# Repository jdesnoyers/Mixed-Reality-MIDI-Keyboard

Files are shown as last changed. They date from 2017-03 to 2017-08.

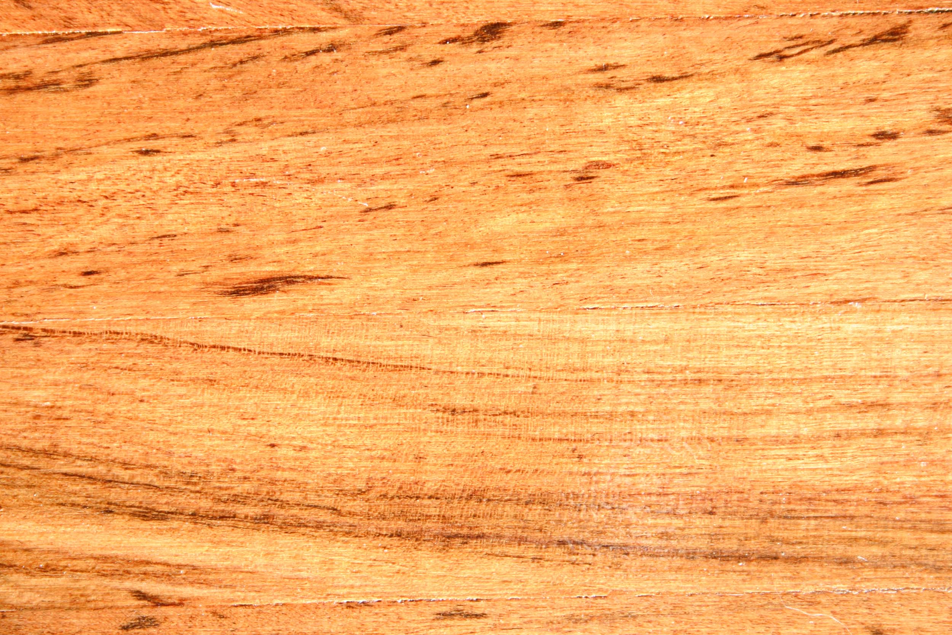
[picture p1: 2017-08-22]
Unity/VR Interactive Keyboard 3/Assets/Models/UV Maps/texturegen_166_6645.jpg

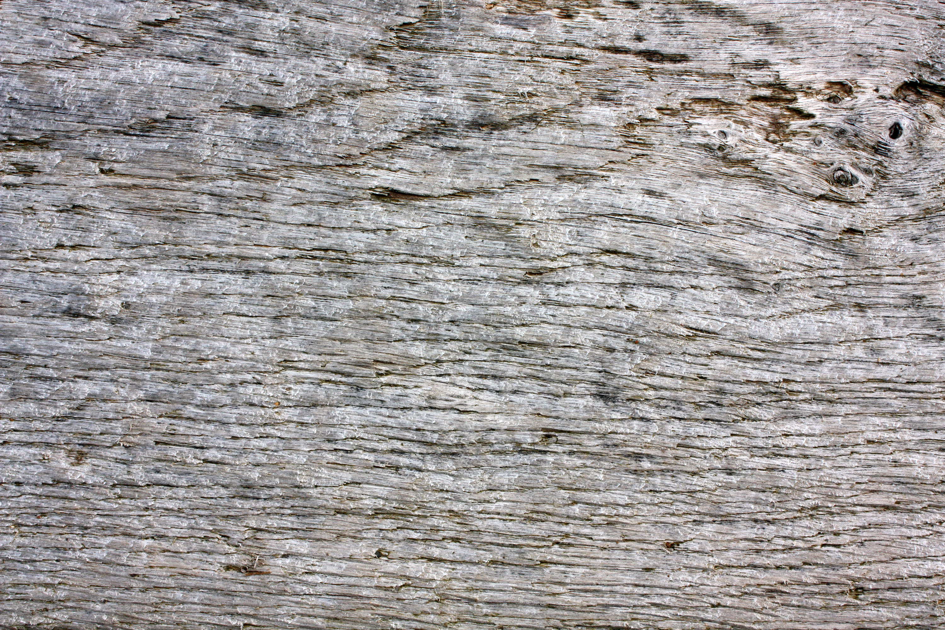
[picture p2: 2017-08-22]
Unity/VR Interactive Keyboard 3/Assets/Models/UV Maps/texturegen_7123.jpg

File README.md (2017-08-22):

# Mixed Reality MIDI Keyboard

This Mixed Reality MIDI Keyboard is an open source system for integrating a MIDI Keyboard into a virtual environment. It includes the design and programming of both the physical keyboard, and the virtual reality environment through which it is interacted with. The system uses a number of devices including the HTC Vive, Vive Tracker, and Leap Motion to locate the user's hands and keyboard.

The keyboard is built from a salvaged keybed, Arduino Mega 2560, and a number of other analog and digital transducers. It communicates using the MIDI protocol, over either MIDI or USB cables allowing it to interface with other stanardized MIDI instruments and digital audio workstations.

## Folders

### Arduino
Program for implementation of physical hardware using Arduino Mega 2560.

### Design Files
3D CAD files, drawings, electrical routing required to build the Keyboard frame and assemble components.

### Unity
Contains required files for Unity project - requires a number of plugins and programs to function properly as listed below:

#### Required Unity Plugins
 - NVIDIA VRWorks
 - TextMesh Pro
 - Leap Motion SDK, hand module and interaction engine module
 
#### Required Programs
 - Unity 2017.1
 - Leap Motion Orion
 - LoopMIDI
 - Hairless MIDIserial
 - Any DAW (Digital Audio Workstation) such as Bitwig Studio or Ableton Live

## Setup

## Operation

---

## Updates

### 10/Aug/2017 - Version 2 - Audio Mostly
This update aligns the software with Version 2 of the physical keyboard. The keyboard has been improved with:
 - matte black interaction surfaces
 - angled upper deck
 - Additional potentiometer and rotary encoder
 - tactile buttons
 - Infrared LEDs with improved, more precise localization capablity

### 27/Mar/2017 - Version 1

#### Changes:
 - Changed to external pull-down resistor configuration in order to simultaneously scan both MK and BR matrices
 - Inputs read directly from registers to reduce scanning time
 - Scanning code optimized to reduce scanning time (currently as low as 470 microseconds when all other functions disabled)
 - MIDI output now sends over USB and MIDI port (TX1)
 - MIDI input (RX1) forwarding to USB
 - Dedicated send/receive MIDI functions
 - #define used in place of constants where possible
 - all variables minimized to take up as little space as possible (eg. using a byte as a boolean array)

#### Additions:
 - 12 input MPR121 Capacitive Array via I2C
 - 60 pixel Adafruit Neopixel LED Strip 
 - Fast LED library to minimize impact on scanning function
 - Pitch Bend control via IR proximity sensor (in progress, may be used as modulation control instead)
 - "Abstraction Layer" slider added
 
#### To Do:
 - Complete Hardware Design & Build
 - Develop Unity based VR platform
 - Integrate MIDI, HTC Vive and Leap Motion
 - Continued Optimization

---

### 27/Feb/2017
Currently a fully functional 61-key midi keyboard with velocity sensing (code is set to 9600 baud for testing)

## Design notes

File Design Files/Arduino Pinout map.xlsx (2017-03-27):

 | Rev 2 |  |  | Resistor to Ground
24 | BR3 | MK3 | 25 | 24 | BR3 | MK3 | 25
26 | MK4 | X | 27 | 26 | MK4 |  | 27
28 | BR4 | X | 29 | 28 | BR4 |  | 29
30 | MK5 | KD0 | 31 | 30 | MK5 |  | 31
32 | BR5 | KD1 | 33 | 32 | BR5 |  | 33
34 | MK6 | KD2 | 35 | 34 | MK6 |  | 35
36 | BR6 | KD3 | 37 | 36 | BR6 |  | 37
38 | MK7 | KD4 | 39 | 38 | MK7 |  | 39
40 | BR7 | KD5 | 41 | 40 | BR7 |  | 41
42 | MK8 | KD6 | 43 | 42 | MK8 |  | 43
44 | BR8 | KD7 | 45 | 44 | BR8 |  | 45
46 | MK9 | BR10 | 47 | 46 | MK9 | BR10 | 47
48 | BR9 | MK10 | 49 | 48 | BR9 | MK10 | 49
 | New
22 | BR3 | MK3 | 23
24 | MK4 | X | 25
26 | BR4 | X | 27
28 | MK5 | KD0 | 29
30 | BR5 | KD1 | 31
32 | MK6 | KD2 | 33
34 | BR6 | KD3 | 35
36 | MK7 | KD4 | 37
38 | BR7 | KD5 | 39
40 | MK8 | KD6 | 41
42 | BR8 | KD7 | 43
44 | MK9 | BR10 | 45
46 | BR9 | MK10 | 47
 | Old
22 | MK10 | BR9 | 23
24 | BR10 | MK9 | 25
26 | KD7 | BR8 | 27
28 | KD6 | MK8 | 29
30 | KD5 | BR7 | 31
32 | KD4 | MK7 | 33
34 | KD3 | BR6 | 35
36 | KD2 | MK6 | 37
38 | KD1 | BR5 | 39
40 | KD0 | MK5 | 41
42 | X | BR4 | 43
44 | X | MK4 | 45
46 | MK3 | BR3 | 47

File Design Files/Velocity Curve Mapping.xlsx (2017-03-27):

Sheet: Sheet1
 |  |  | dTmin | 2442 | resolution
Distance | 0.0001 m |  | dTmax | 100400 | 41.11384111
Delta T (uS) | Velocity | midi out (-127/1040) | midi out (dTmin)
814 | 1.228501229 | 135.5789224 | 129.1106597
1628 | 0.6142506143 | 131.1394593 | 128.0553298
2442 | 0.4095004095 | 126.8422173 | 127
3256 | 0.3071253071 | 122.6826401 | 125.9446702
4070 | 0.2457002457 | 118.6563175 | 124.8893403
4884 | 0.2047502048 | 114.7589808 | 123.8340105
5698 | 0.1755001755 | 110.9864977 | 122.7786807
6512 | 0.1535626536 | 107.3348684 | 121.7233508
7326 | 0.1365001365 | 103.8002214 | 120.668021
8140 | 0.1228501229 | 100.3788091 | 119.6126912
8954 | 0.1116819299 | 97.06700384 | 118.5573613
9768 | 0.1023751024 | 93.86129435 | 117.5020315
10582 | 0.0945000945 | 90.75828179 | 116.4467016
11396 | 0.08775008775 | 87.75467618 | 115.3913718
12210 | 0.0819000819 | 84.84729298 | 114.336042
13024 | 0.07678132678 | 82.03304962 | 113.2807121
13838 | 0.07226477815 | 79.30896233 | 112.2253823
14652 | 0.06825006825 | 76.67214288 | 111.1700525
15466 | 0.06465795939 | 74.11979561 | 110.1147226
16280 | 0.06142506143 | 71.64921439 | 109.0593928
17094 | 0.0585000585 | 69.25777979 | 108.004063
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

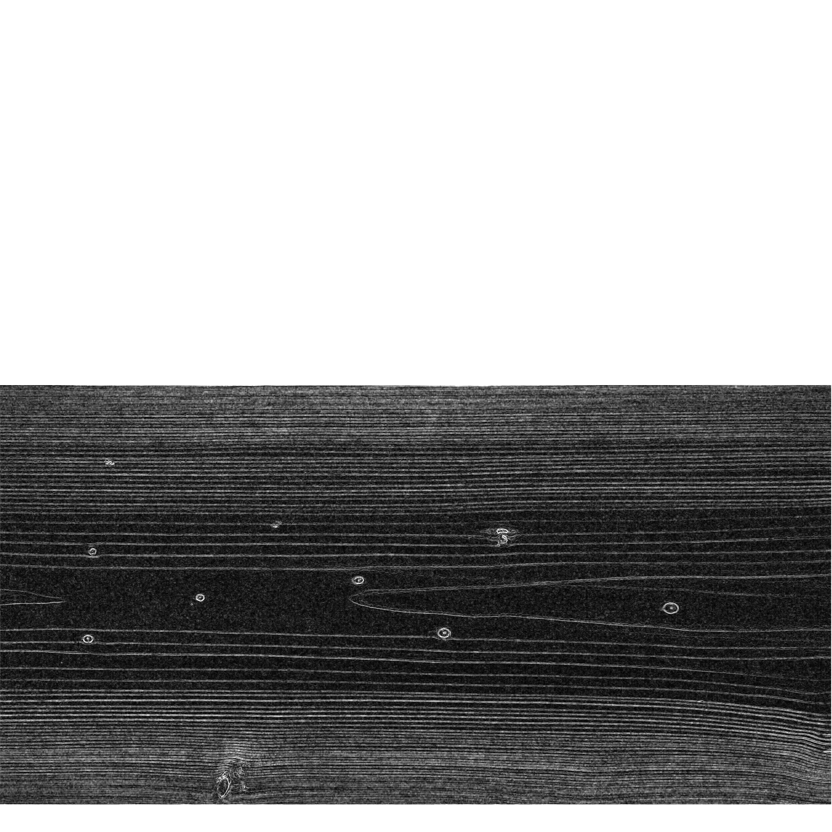
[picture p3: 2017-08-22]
Unity/VR Interactive Keyboard 3/Assets/Models/UV Maps/MR MIDI Keyboard - End Piece Specular.png

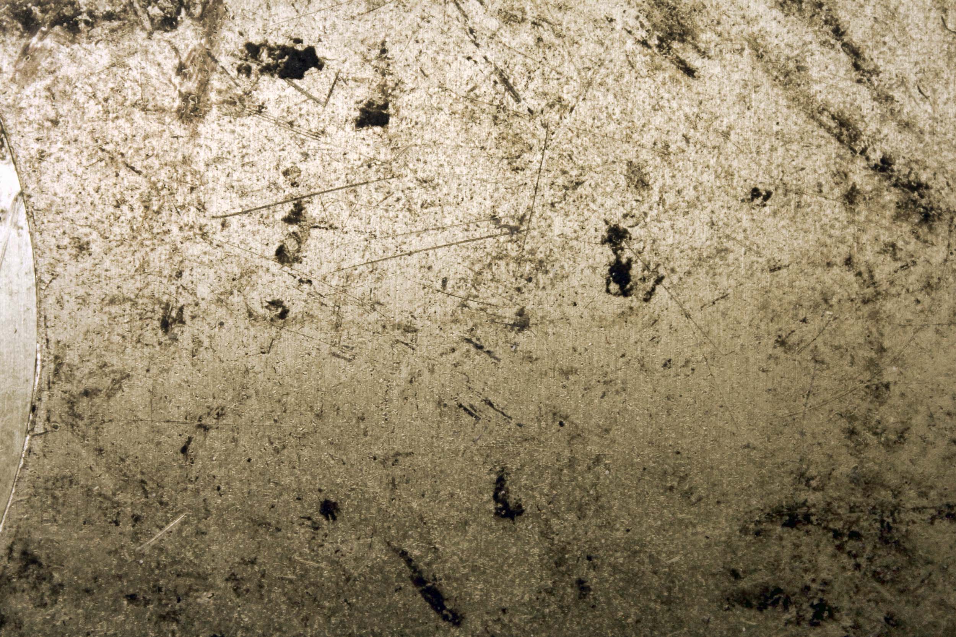
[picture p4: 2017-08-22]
Unity/VR Interactive Keyboard 3/Assets/Models/UV Maps/texturegen_w1098.jpg

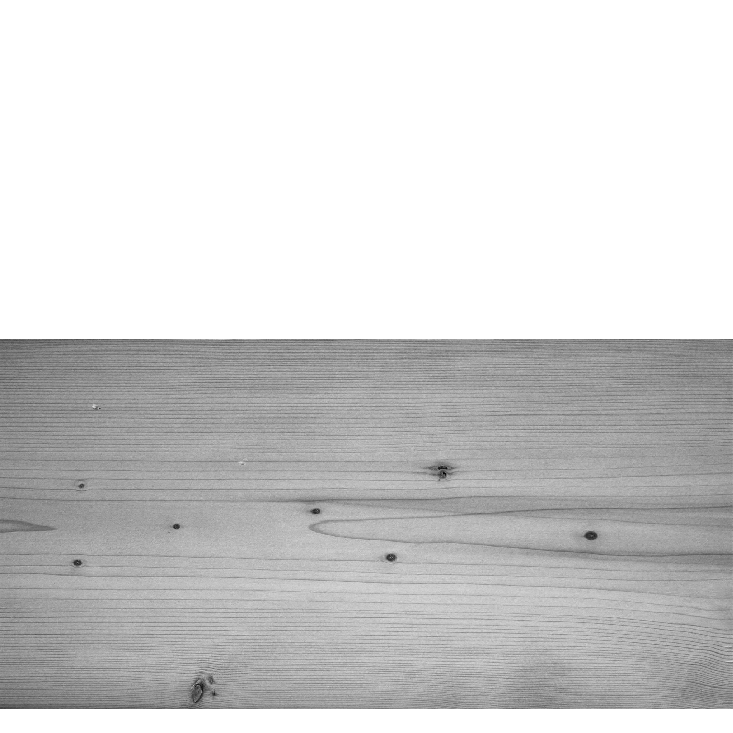
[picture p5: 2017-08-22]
Unity/VR Interactive Keyboard 3/Assets/Models/UV Maps/MR MIDI Keyboard - End Piece Bump.png

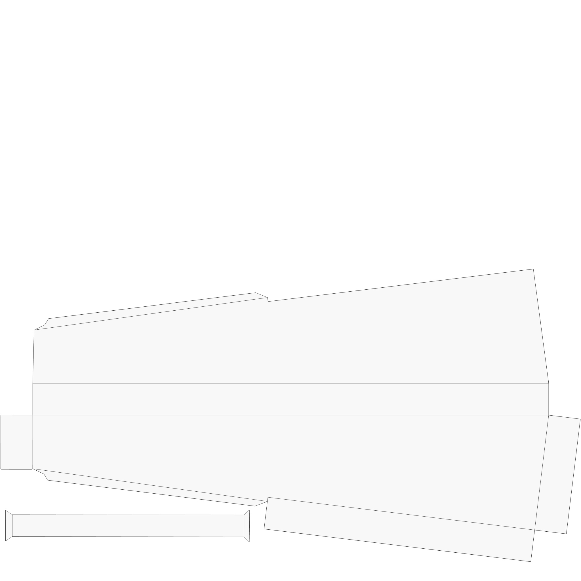
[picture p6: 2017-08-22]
Unity/VR Interactive Keyboard 3/Assets/Models/UV Maps/MR MIDI Keyboard - End Piece UV.png

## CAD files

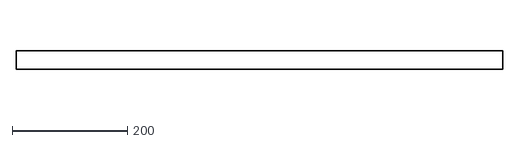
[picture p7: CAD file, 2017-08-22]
Design Files/Mechanical/Outlines/Keyboard Parts - Reinforcement-Rear.dxf
842.0 x 31.8

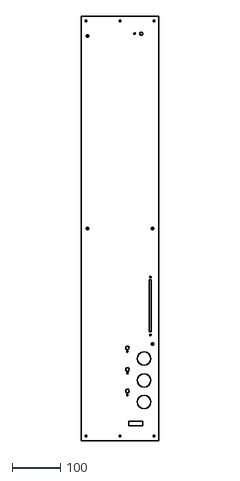
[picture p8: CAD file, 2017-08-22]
Design Files/Mechanical/Outlines/Keyboard Parts - Top Panel.dxf
160.4 x 882.0

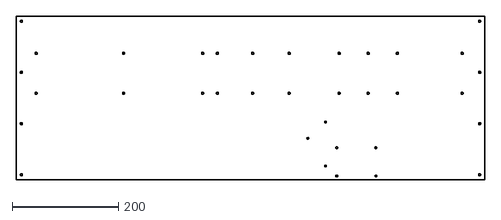
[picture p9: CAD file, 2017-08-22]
Design Files/Mechanical/Outlines/Keyboard Parts - Base Panel.dxf
882.0 x 308.0

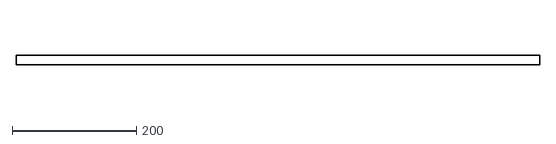
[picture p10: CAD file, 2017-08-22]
Design Files/Mechanical/Outlines/Keyboard Parts - Reinforcement-Front.dxf
842.0 x 15.9

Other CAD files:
Unity/VR Interactive Keyboard 3/Assets/Models/MR MIDI Keyboard.blend

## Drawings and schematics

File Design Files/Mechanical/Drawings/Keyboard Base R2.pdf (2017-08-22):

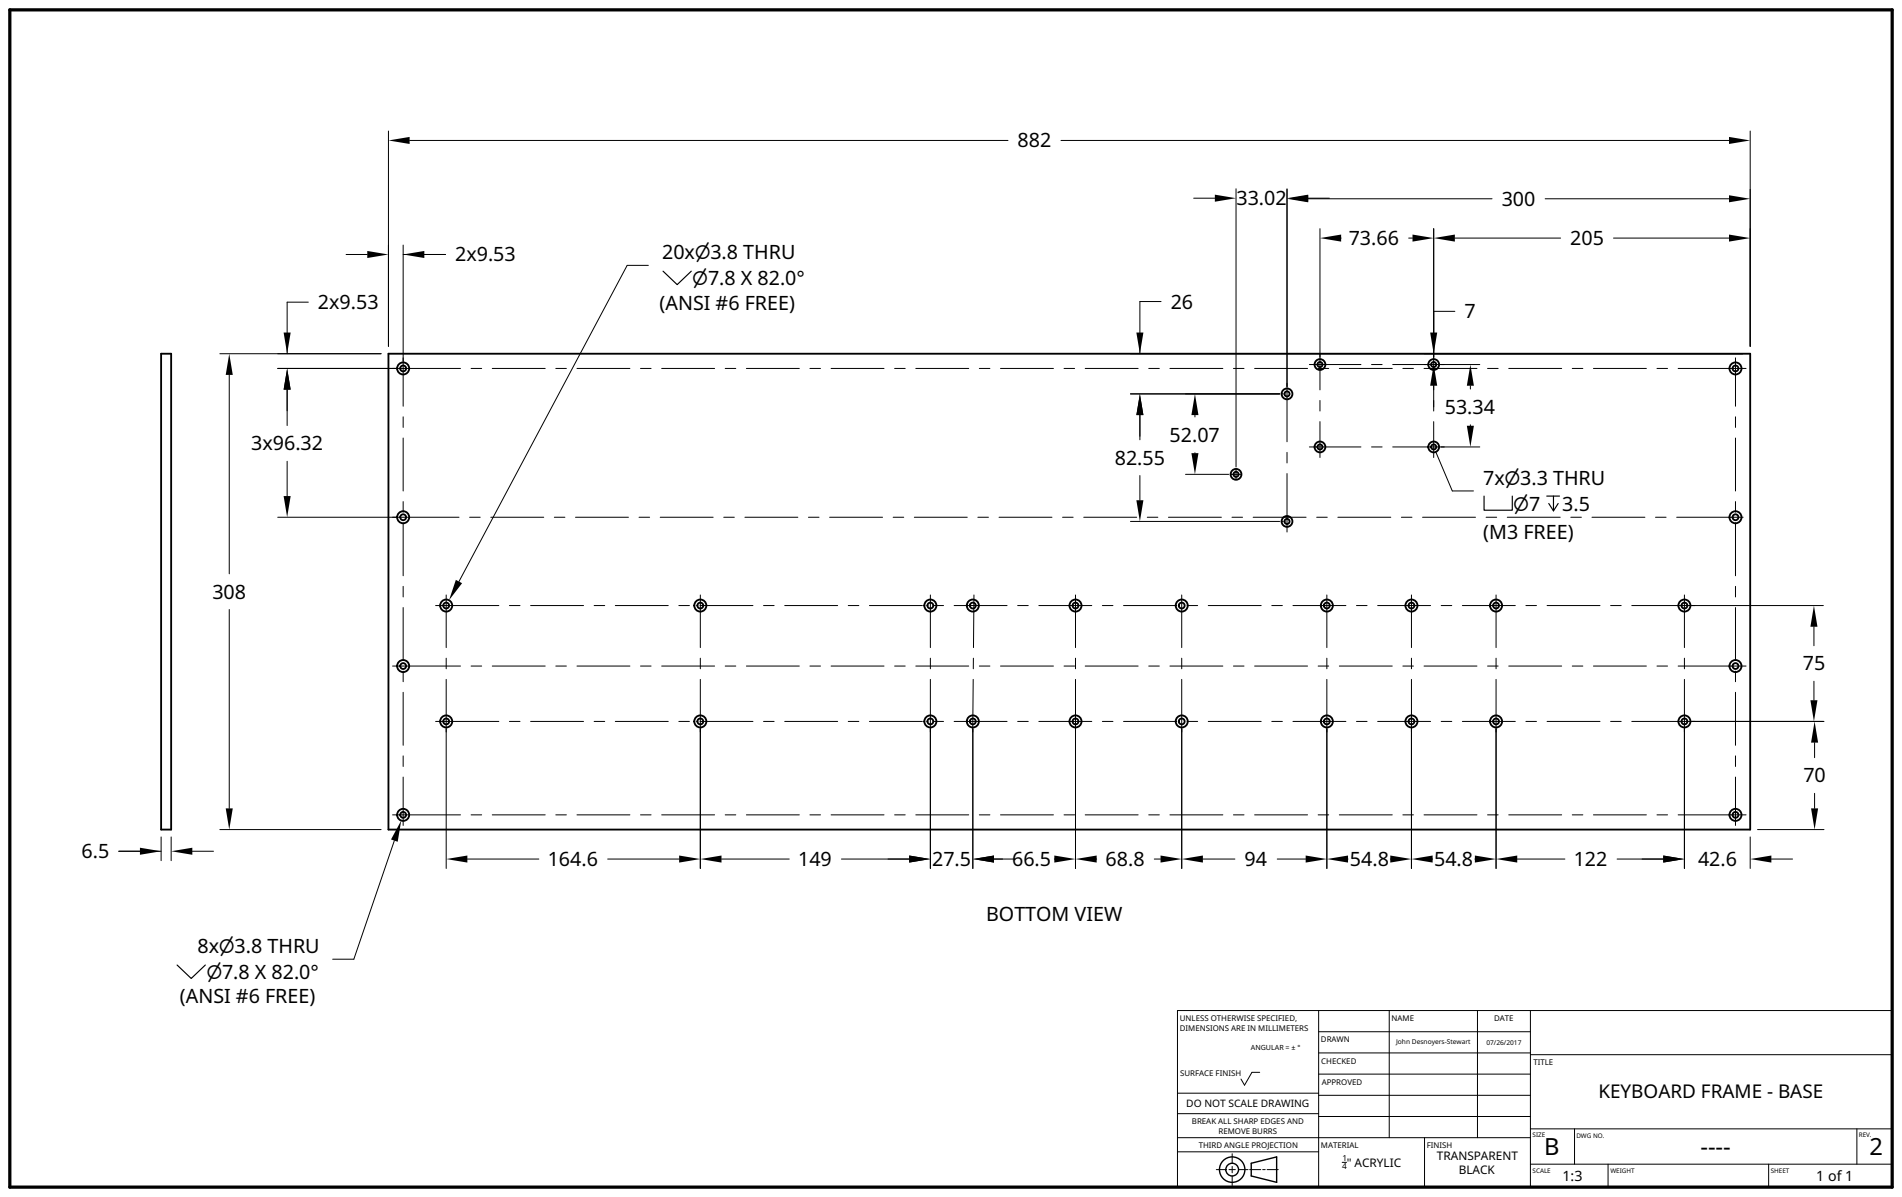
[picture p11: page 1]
MATERIAL; 1 4" ACRYLIC; FINISH TRANSPARENT BLACK; BOTTOM VIEW; 8x3.8 THRU w7.8 X 82.0°; 20x3.8 THRU w7.8 X 82.0° (ANSI #6 FREE); (ANSI #6 FREE); (M3 FREE); 7x3.3 THRU v7 x3.5

UNLESS OTHERWISE SPECIFIED, DIMENSIONS ARE IN MILLIMETERS ANGULAR = ± ° SURFACE FINISH | | NAME | DATE

DRAWN | John Desnoyers-Stewart | 07/26/2017

CHECKED | | | TITLE KEYBOARD FRAME - BASE

APPROVED

DO NOT SCALE DRAWING

BREAK ALL SHARP EDGES AND

REMOVE BURRS
THIRD ANGLE PROJECTION

SIZE B | DWG NO. ---- | REV. 2

SCALE 1:3 | WEIGHT | SHEET

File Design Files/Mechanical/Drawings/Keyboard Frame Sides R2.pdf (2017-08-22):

2x70.67

9.53

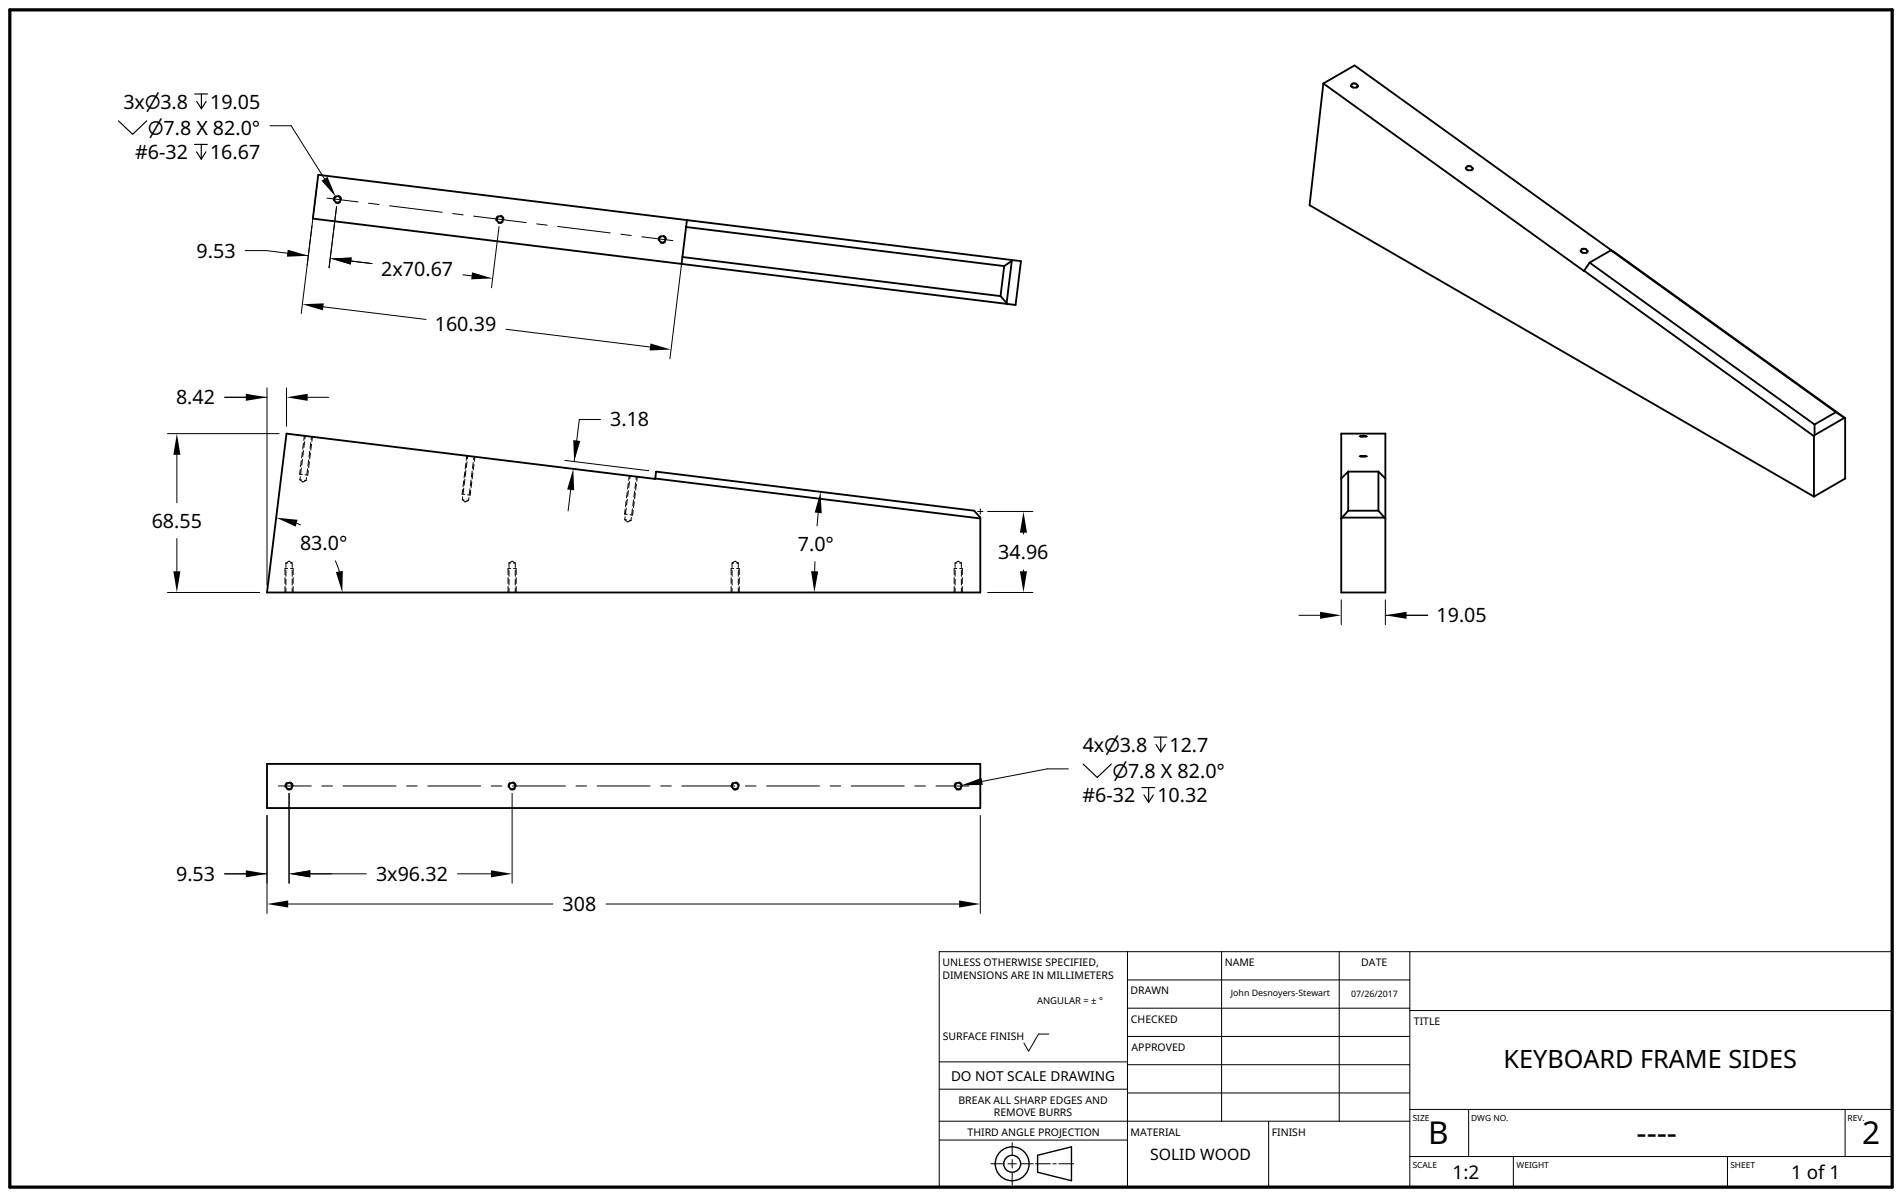
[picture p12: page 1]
MATERIAL SOLID WOOD; FINISH

UNLESS OTHERWISE SPECIFIED, DIMENSIONS ARE IN MILLIMETERS ANGULAR = ± ° SURFACE FINISH | | NAME | DATE

DRAWN | John Desnoyers-Stewart | 07/26/2017

CHECKED | | | TITLE KEYBOARD FRAME SIDES

APPROVED

DO NOT SCALE DRAWING

BREAK ALL SHARP EDGES AND

REMOVE BURRS
THIRD ANGLE PROJECTION

SIZE B | DWG NO. ---- | REV. 2

SCALE 1:2 | WEIGHT | SHEET

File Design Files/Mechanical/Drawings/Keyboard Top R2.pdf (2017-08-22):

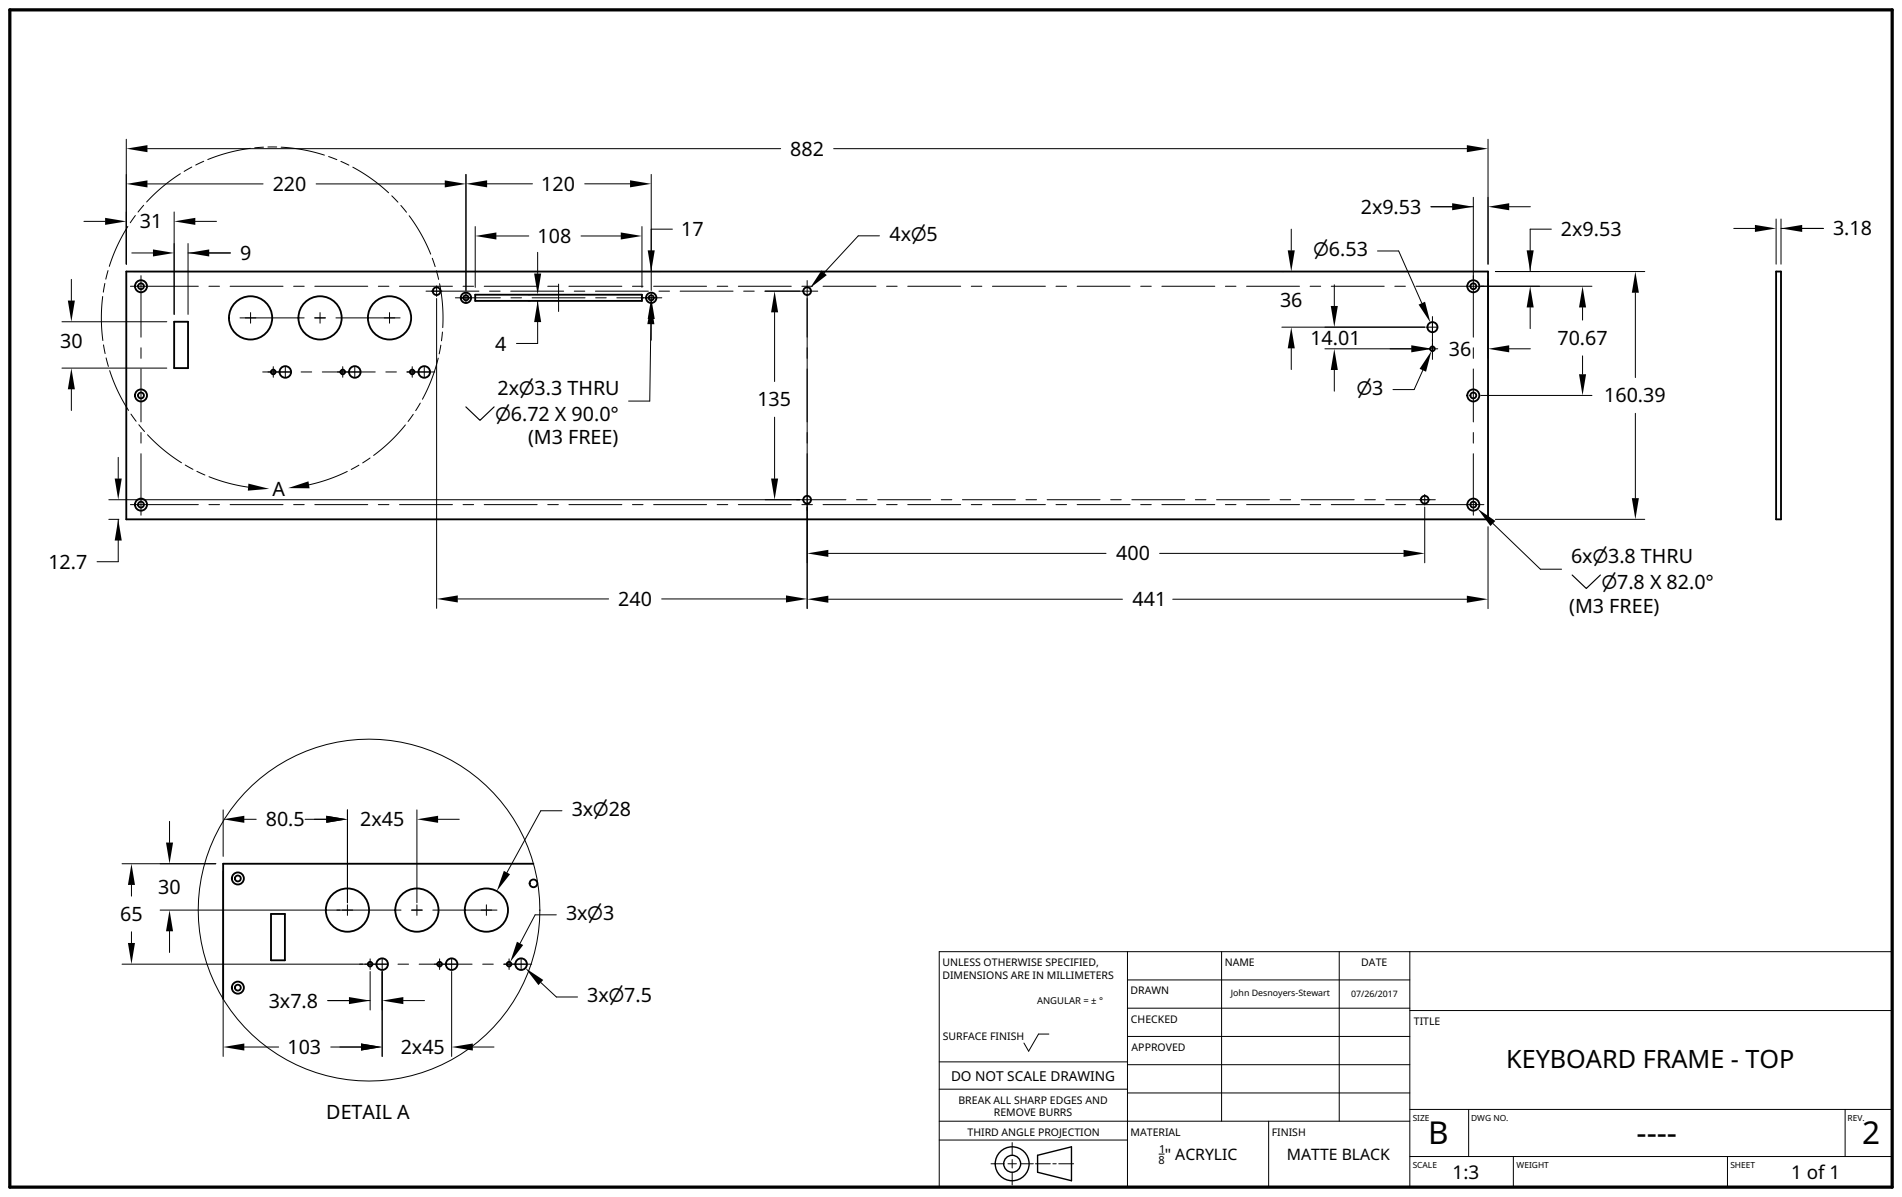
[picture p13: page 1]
MATERIAL 1 8" ACRYLIC; FINISH MATTE BLACK; DETAIL A; 2x3.3 THRU w6.72 X 90.0° (M3 FREE); 6x3.8 THRU w7.8 X 82.0° (M3 FREE)

UNLESS OTHERWISE SPECIFIED, DIMENSIONS ARE IN MILLIMETERS ANGULAR = ± ° SURFACE FINISH | | NAME | DATE

DRAWN | John Desnoyers-Stewart | 07/26/2017

CHECKED | | | TITLE KEYBOARD FRAME - TOP

APPROVED

DO NOT SCALE DRAWING

BREAK ALL SHARP EDGES AND

REMOVE BURRS
THIRD ANGLE PROJECTION

SIZE B | DWG NO. ---- | REV. 2

SCALE 1:3 | WEIGHT | SHEET

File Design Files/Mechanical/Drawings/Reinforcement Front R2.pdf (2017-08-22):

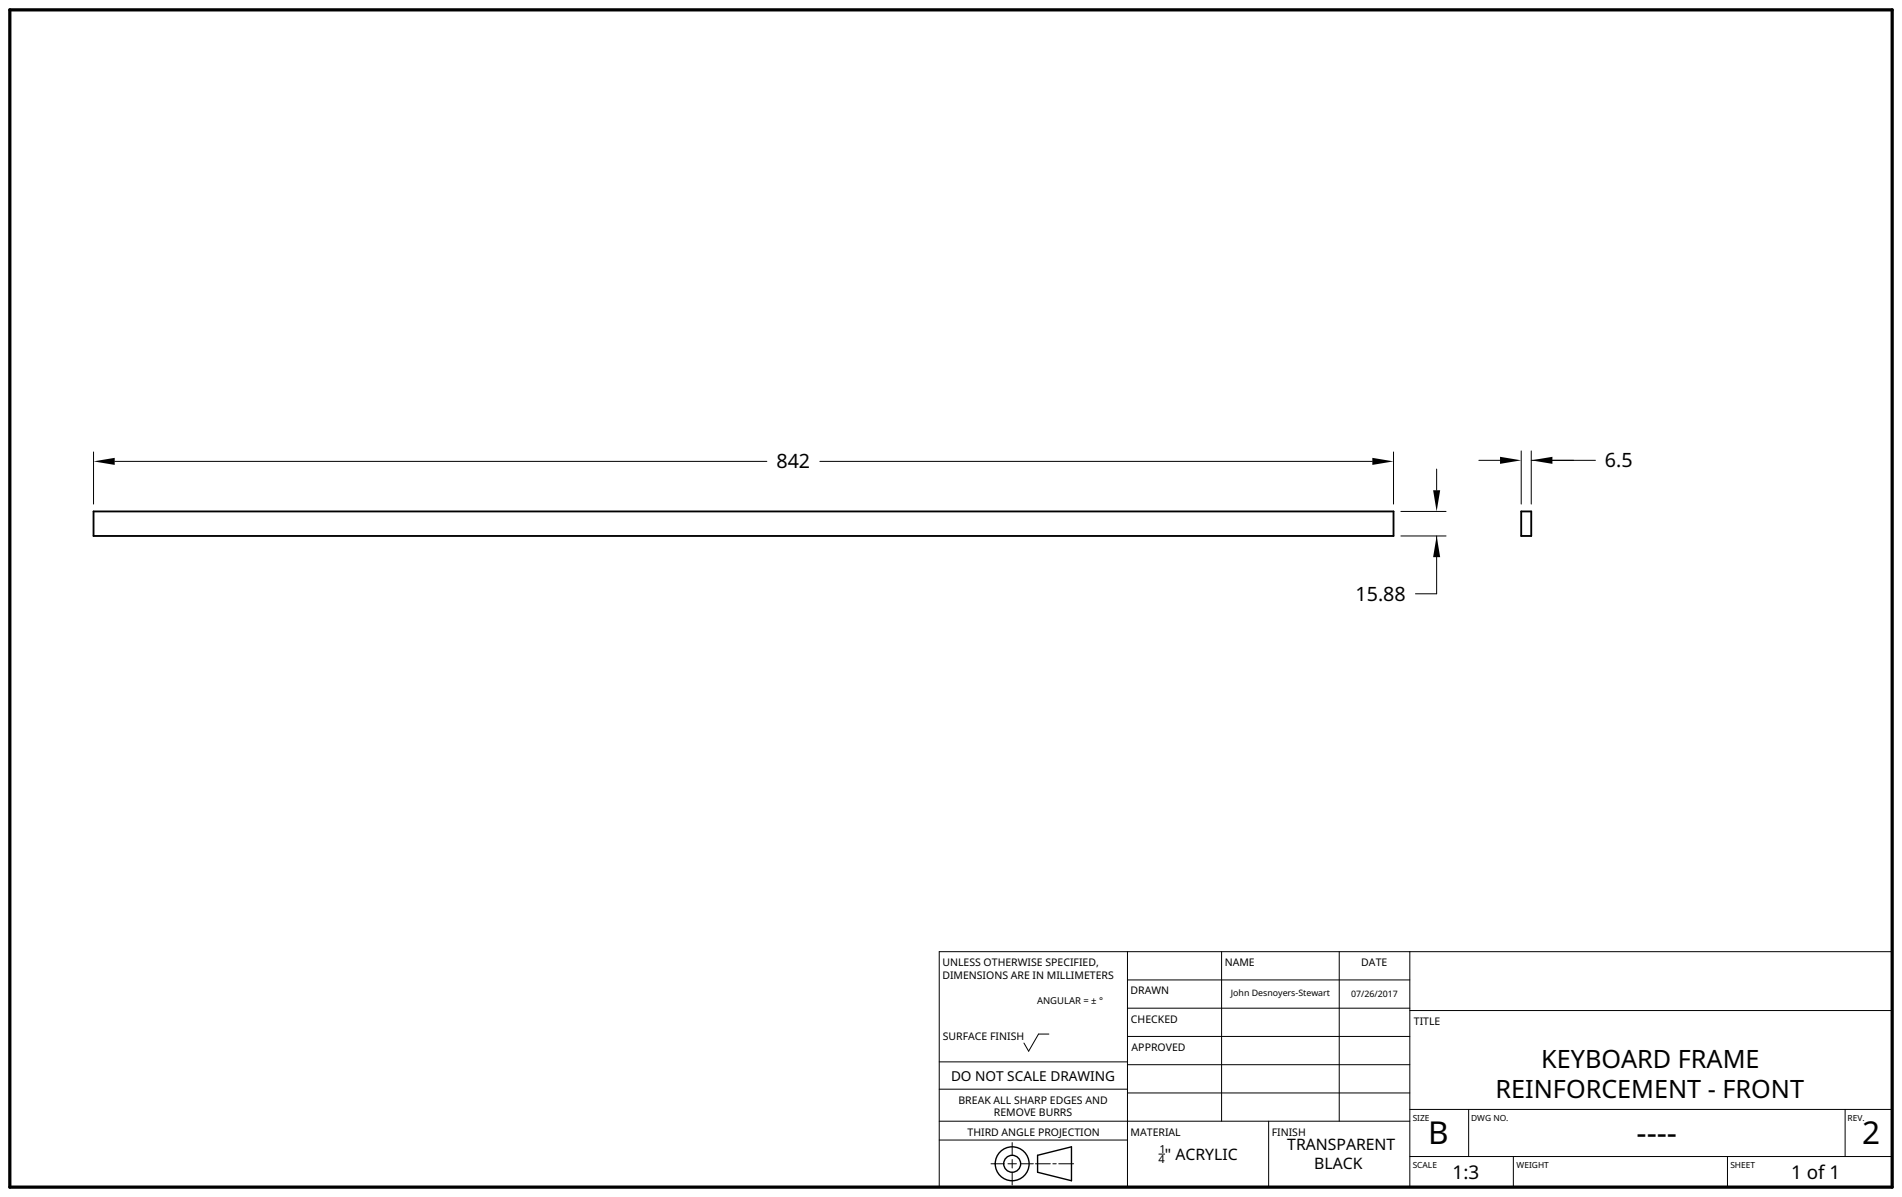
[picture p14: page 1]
MATERIAL 1 4" ACRYLIC; FINISH TRANSPARENT BLACK

UNLESS OTHERWISE SPECIFIED, DIMENSIONS ARE IN MILLIMETERS ANGULAR = ± ° SURFACE FINISH | | NAME | DATE

DRAWN | John Desnoyers-Stewart | 07/26/2017

CHECKED | | | TITLE KEYBOARD FRAME REINFORCEMENT - FRONT

APPROVED

DO NOT SCALE DRAWING

BREAK ALL SHARP EDGES AND

REMOVE BURRS
THIRD ANGLE PROJECTION

SIZE B | DWG NO. ---- | REV. 2

SCALE 1:3 | WEIGHT | SHEET

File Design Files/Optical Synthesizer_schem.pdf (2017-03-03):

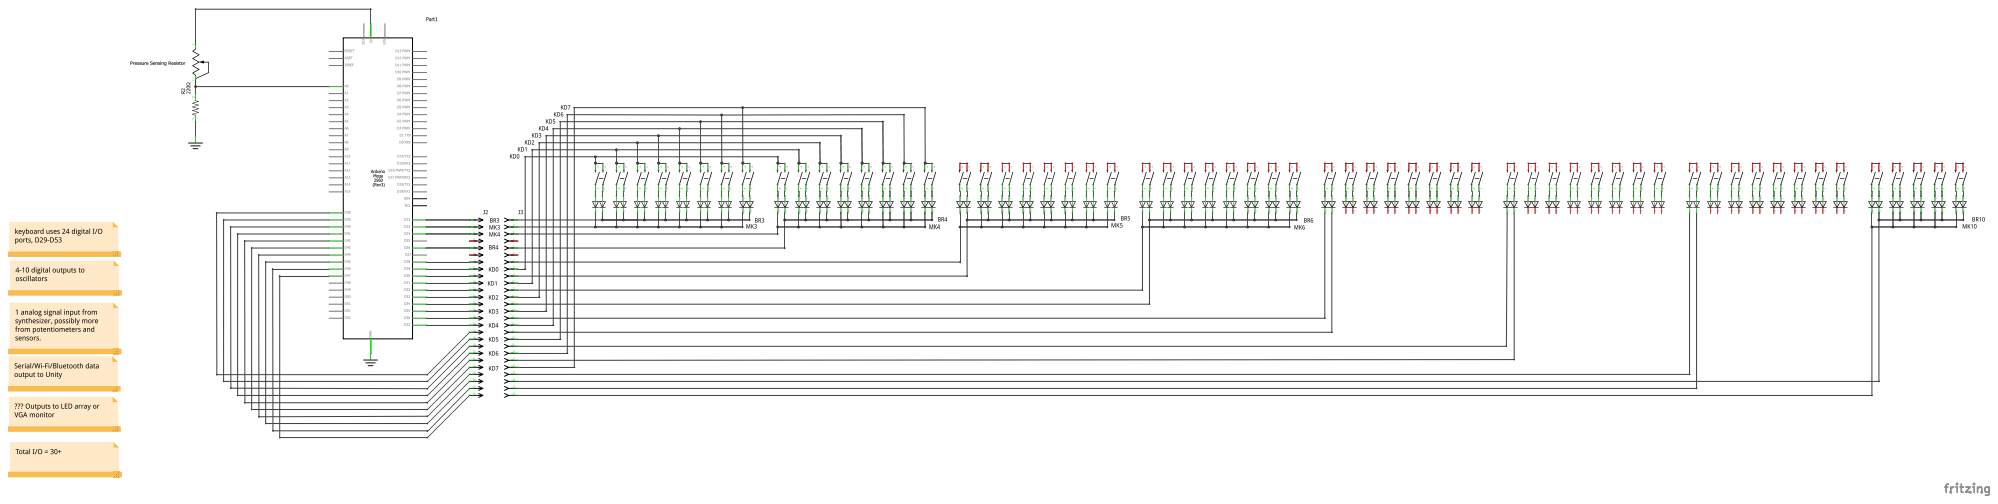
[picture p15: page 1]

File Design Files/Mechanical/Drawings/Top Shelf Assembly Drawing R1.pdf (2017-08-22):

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

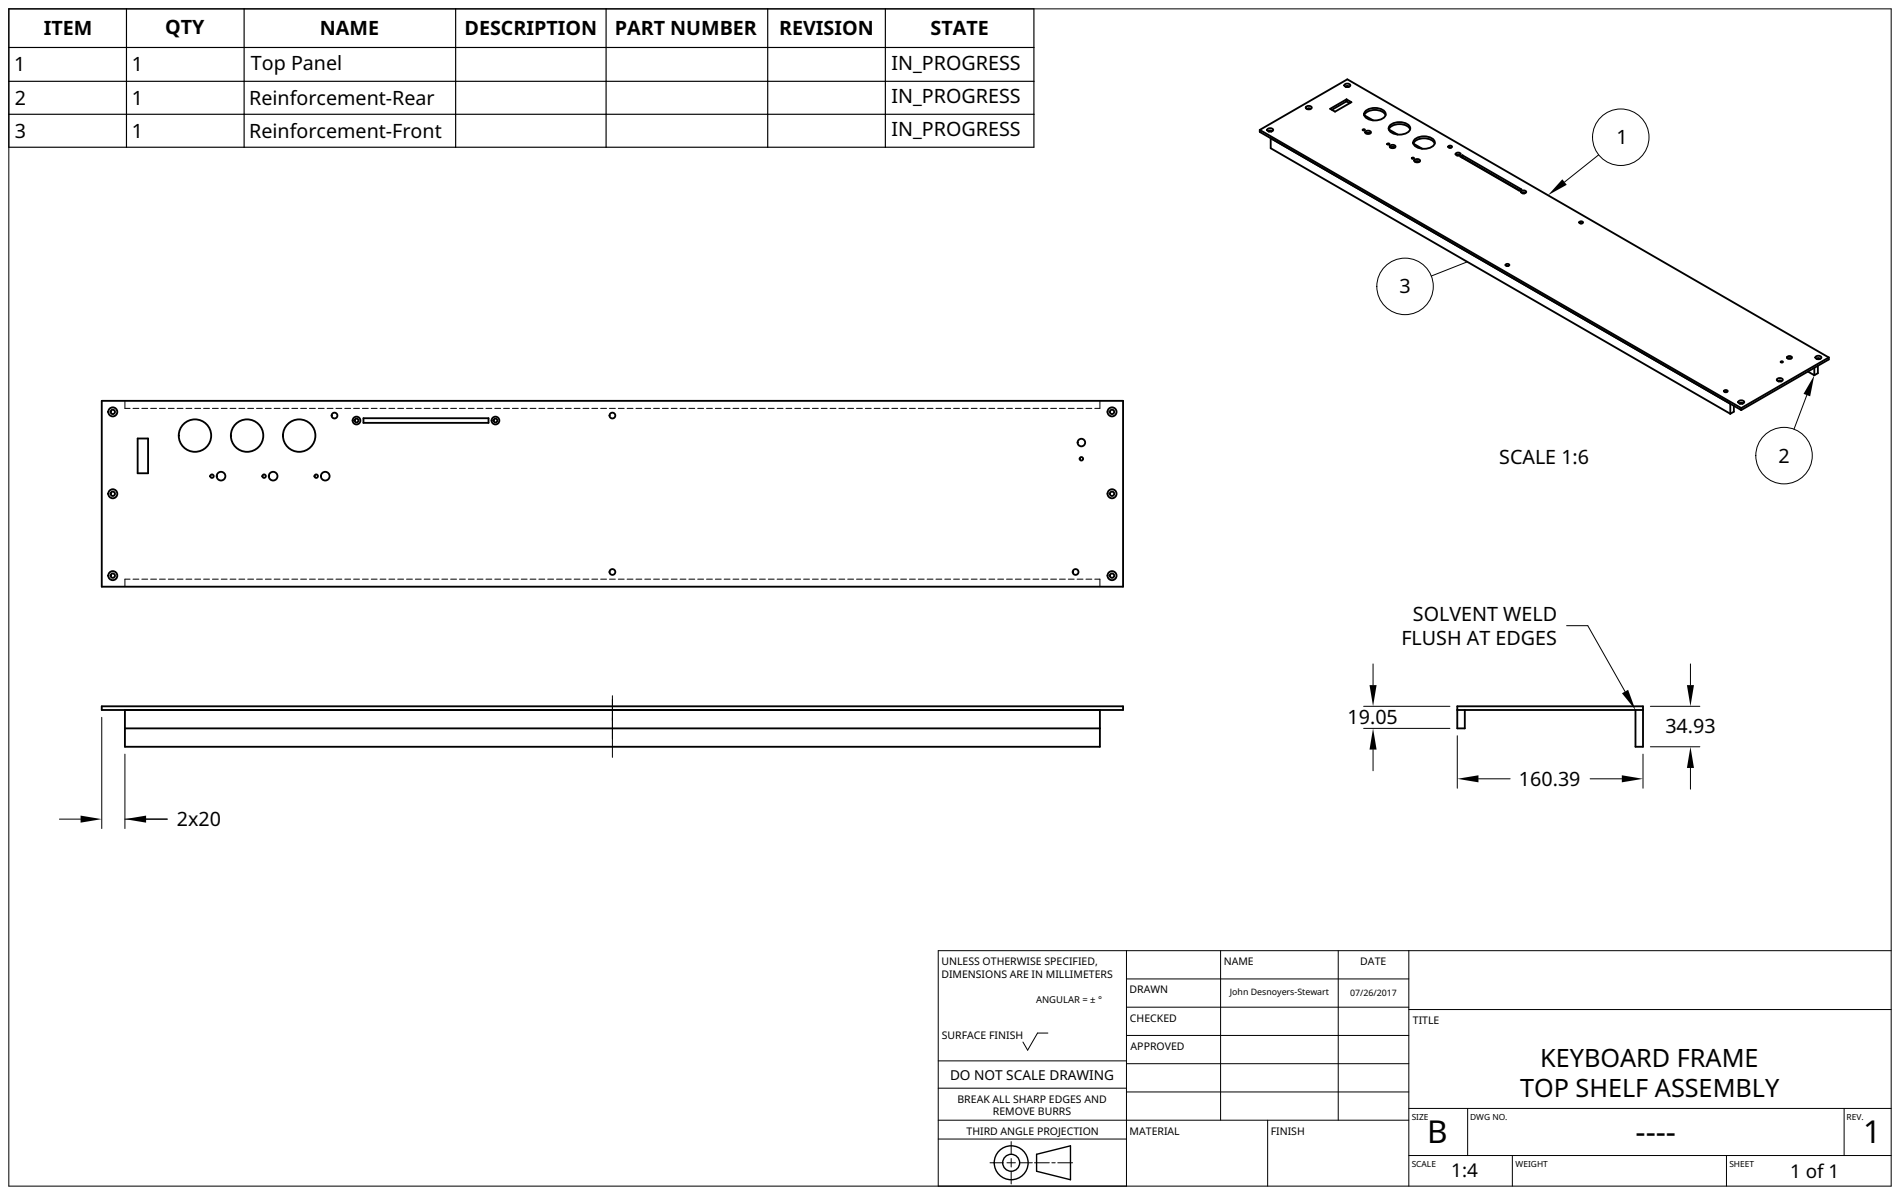
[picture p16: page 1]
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

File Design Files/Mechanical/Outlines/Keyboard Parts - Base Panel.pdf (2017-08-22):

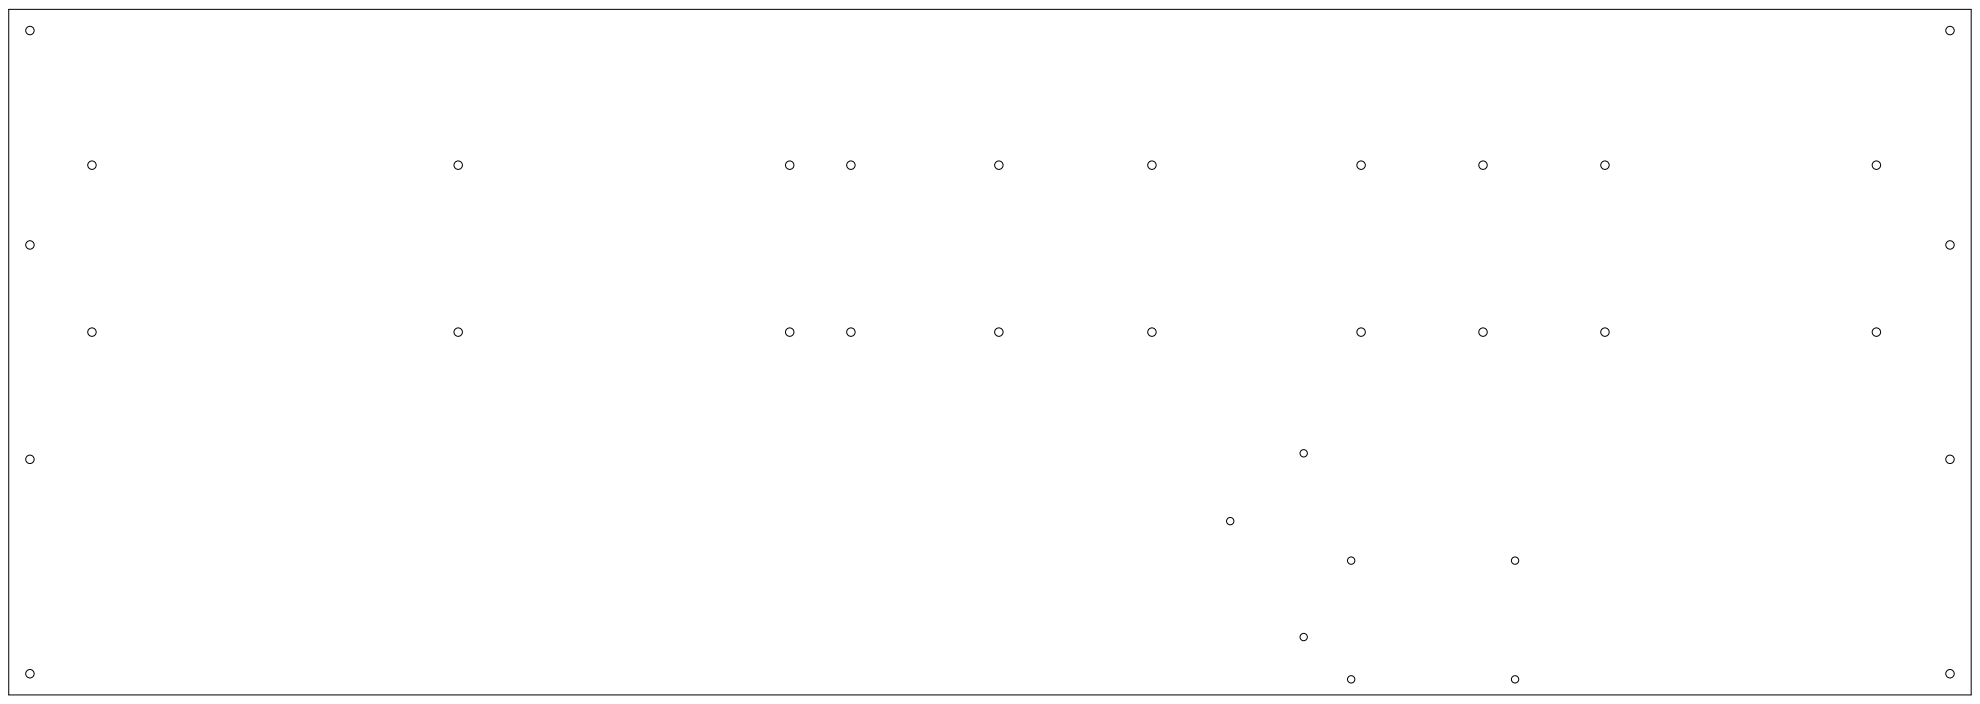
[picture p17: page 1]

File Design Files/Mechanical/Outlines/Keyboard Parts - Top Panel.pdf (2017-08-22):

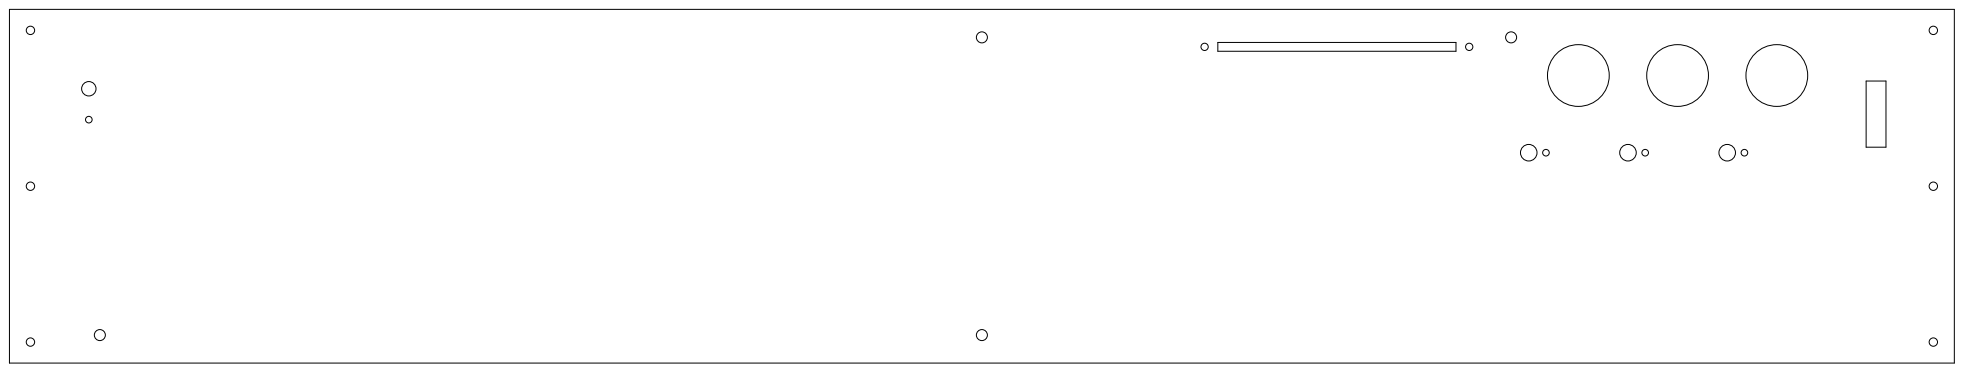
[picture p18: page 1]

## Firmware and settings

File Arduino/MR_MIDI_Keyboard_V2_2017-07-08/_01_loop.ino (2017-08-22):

void loop() {
  
  scanRow(rownum);  //scan row on every cycle

  if(rownum >=7)  //perform other operations once per matrix scan
  {
    rownum=0;
    midiAftertouch();
    midiAbstractionLayer();
    midiCutoffFrequency();
    midiResonance();
    #if(CAP_ARRAY_ACTIVE==1)
      midiCapArray();
    #endif
    midiButtonArray();
    midiPitchBend();
    midiEncoder();
    colorizeEnds();
    FastLED.show(); //activate current LEDs
    //speedCheck();
  }
  else
    rownum++;

}

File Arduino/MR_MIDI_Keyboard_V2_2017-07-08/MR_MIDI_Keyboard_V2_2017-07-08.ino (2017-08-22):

#include <Wire.h>
#include <Adafruit_MPR121.h>
#include <FastLED.h>

#define USB_DEBUG_MODE 0    //1 activates USB debug mode, 0 deactivates for MIDI transmission
#define CAP_ARRAY_ACTIVE 1 //1 activates capacitive sensor array (blocks startup if disconnected), 0 turns off
#define LEFT_LED_ACTIVE 1 //1 activates the left (fourth) LED, 0 deactivates

#define NUM_LEDS 52             //Number of LEDs in Neopixel strip
#define START_KEYLEDS 0         //Start of Keyboard aligned LEDs
#define NUM_KEYLEDS 50          //Number of Keyboard aligned LEDs
#define DELTA_T_MAX 106608      //set max velocity sensing time
#define DELTA_T_MIN 2416        //set min veloicty sensing time
#define SMOOTHING_ARRAY_SIZE 10 //smoothing array moving average
#define ENCODER_ARRAY_SIZE 8    //size of encoder control array
#define ENCODER_ACCEL_TIME 50 //what is the threshold for a "fast" count vs a "slow" count
#define ENCODER_INCREMENT_MAX 16 //maximum increment per encoder pulse

//analog pin definitions
#define ABSTRACTION_POT_PIN A0  //"Abstraction" Linear Potentiometer analog input pin
#define CUTOFF_POT_PIN A1       //Frequency cutoff rotary potentiometer pin
#define RESONANCE_POT_PIN A2    //Resonance rotary potentiometer pin
#define PITCHBEND_PIN A3        //IR pitchbend sensor pin
#define AFTERTOUCH_PIN A15      //Keyboard aftertouch pin

//digital pin definitions - NOTE: PINS 24-49 dedicated to keyboard
#define ENCODER_CHAN_A 2        //Rotary encoder channel A
#define ENCODER_CHAN_B 3        //Rotary encoder channel B
#define LED_DATA_PIN 8          //LED serial communication pin
#define IR_LED_PIN_A 9          //Infrared LED pin A (RIGHT)
#define IR_LED_PIN_B 10         //Infrared LED pin B (MIDDLE)
#define IR_LED_PIN_C 11         //Infrared LED pin C (LEFT)
#define ABSTRACTION_LED_PIN 12  //"Abstraction" Linear Potentiometer LED output pin
#define ARCADE_BUTTON_01 50     //Arcade button pin 1
#define ARCADE_BUTTON_02 51     //Arcade button pin 2
#define ARCADE_BUTTON_03 52     //Arcade button pin 3
#define ENCODER_BUTTON 53        //Rotary encoder button

/* 61 key Mixed Reality MIDI Keyboard
 * 
 * FOR ARDUINO MEGA 2560
 * 
 * John Desnoyers-Stewart
 * 
 * V2 August 6, 2017
 * V1 April 5, 2017
 * 
 * Use of KD, BR and MK correspond to keyboard matrix PCB
 * KD is output (activated rows) and BR and MK are input (scanned columns)
 * Two parallel 8x8 matrices, KDxBR and KDxMK
 */

//prototypes

void scanRow(byte row);                             //scans one row of key matrix
byte calculateVelocity(unsigned long keytimeCalc);  //calculates velocity based on switch timing
void speedCheck();                                  //used to test speed of the device

void midiOn(byte key,byte vel);   //generate MIDI on signal
void midiOff(byte key,byte vel);  //generate MIDI off signal
void midiAftertouch();            //convert aftertouch information to MIDI data
void midiCutoffFrequency();       //convert analog input to MIDI cutoff freq.
void midiResonance();             //convert analog input to MIDI resonance freq.
void midiPitchBend();             //convert IR prox sensor to MIDI pitch bend
void midiAbstractionLayer();      //send abstraction layer data over MIDI
void midiCapArray();              //send capacitive touch data over MIDI
void midiButtonRead();            //send button presses over MIDI
void encoderPinA();               //interrupt function for encoder pin a
void encoderPinB();               //interrupt function for encoder pin b
void midiEncoder();               //send encoder data over MIDI;
void smoothAnalogReadMIDI(uint16_t readarray[], byte& index, byte& smoothedvalue, byte factor, byte pin, int maxvolt = 1023);   //reads an analog value and smooths the number via an array

void sendMidiData(byte midiStatus,byte midiDataA,byte midiDataB); //send three byte midi signal
void sendMidiData(byte midiStatus,byte midiDataA);                //overload to send two byte midi signal

void activateLED(byte led, byte vel); //activate LED based on key press
void deactivateLED(byte led);         //deactivate on release

const byte matrixKD[8] = {31,33,35,37,39,41,43,45}; //define matrix rows

//scanned rows BR,MK pins - array 0-8 corresponds to board numbers 3-10
//const byte matrixBR[8] = {24,28,32,36,40,44,48,47};
//const byte matrixMK[8] = {25,26,30,34,38,42,46,49};

long loopTime = 0;  //time tracking variable

byte rownum = 0;  //current row number for activating BR/MK3-10

//matrix read/write bytes
byte inputBR = 0; //each bit captures the current state of a key within the current scan
byte inputMK = 0;
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

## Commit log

2017-03-27 Add files via upload
    Update to schematics to match current hardware use. Changed from internal pull-up configuration to external pull-down resistors in order to speed up matrix scan operation. Prototype is now built onto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
    Added inputs: linear pot, rotational pot, touch pot, pressure sensing resistor, 12 element capacitive sensing.
    Added outputs: array of 60 neopixel RGB LEDs
    Added communication: MIDI in and out
    [Arduino Pinout map.xlsx, Optical Synthesizer.fzz, Velocity Curve Mapping.xlsx]
2017-03-28 Add files via upload
    ***MAJOR UPDATE***
    Changes:
    - Changed to external pull-down resistor configuration in order to simultaneously scan both MK and BR matrices
    - Inputs read directly from registers to reduce scanning time
    - Scanning code optimized to reduce scanning time (currently as low as 470 microseconds when all other functions disabled)
    - MIDI output now sends over USB and MIDI port (TX1)
    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
2017-04-09 Update-20170408
    Removed unneeded files
    Added mechanical drawings
    Added Functionality to keyboard code:
    - Average of pressed colours displayed at ends
    - IR Tracking mode enabled by pressing cap array button 1
    - Cap array buttons 1-3 now toggles (switch from 0-1 on each press
    - Rotary potentiometer used as cutoff input
    - Code for IR distance sensor as pitch-bend added, still needs some smoothing
    - Reference to internal Arduino capsensing removed as it slows things down too much
    * Delete _00_scanning_functions.ino
    * Delete _01_midi_functions.ino
    * Add files via upload
    * Add files via upload
    * Add files via upload
    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
    [Optical Synthesizer.fzz]
2017-08-22 MR MIDI Keyboard V2 2017 08 22 (#2)
    * Delete CS890EH-CS207 Project Proposal.pdf
    * Delete Salvaged Keybed.jpg
    * Updating to match current hardware design
    Updates to Arduino code and design files improve the tracking, add more physical controls and refine the appearance of MR MIDI Keyboard V2.
    * Mixed Reality MIDI Keyboard V2 Unity updates
    updating unity files to match Mixed Reality MIDI Keyboard
    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
    [Keyboard Parts - Base Panel.dxf, Keyboard Parts - Reinforcement-Front.dxf, Keyboard Parts - Reinforcement-Rear.dxf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]
